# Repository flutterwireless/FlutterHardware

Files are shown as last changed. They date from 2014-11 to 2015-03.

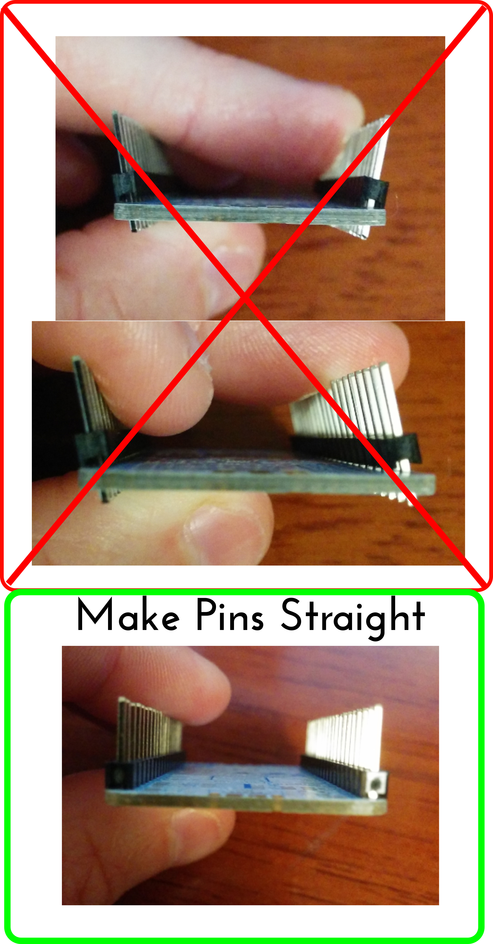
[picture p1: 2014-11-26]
Boards/FlutterBasic/gerber/Solder pins.jpg

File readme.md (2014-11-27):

Flutter Wireless Open Source Hardware files
==============

Flutter Wireless is an open source hardware platform designed by Taylor Alexander for the development of mesh networking protocols and connected devices. It is intended for use in robotics, hobbyist, commercial, or educational applications. For more information visit [FlutterWireless.com](http://www.flutterwireless.com/). All files copyright Flutter Wireless, 2013-2015.

Instructions
----------

If you want to modify these files, you need a version of EagleCAD that can work with 4 layer files (the freeware version only supports 2 layers). They have a [hobby license](http://www.cadsoftusa.com/shop/eagle-hobbyist-and-education/?lang=en) that is well-suited for this. If you only want to reproduce the boards as is, we have provided gerber files. Note that the files do not have a clean perimeter as they are intended to be arrayed on a panel. We will probably revert to a non panel-ready version at some point, as I don't believe our assembler needs them to be that way. Please file an issue if you cannot use them in their current format.

License
--------

This is the initial release of the hardware design files. They are licensed under Creative Commons Attribution-ShareAlike 4.0 International (CC BY-SA 4.0), which is available at: http://creativecommons.org/licenses/by-sa/4.0/
If you use the files, please check them carefully - they may contain errors.

Legal
--------

These documents are provided for informational purposes only and neither Flutter Wireless nor its employees, contributors, or representatives may be held liable for any damages caused by the use of these files. By using these files, you agree to release from all liability and hold harmless Flutter Wireless, its employees, contributors, and representatives. We are not responsible for any errors or ommissions contained herin, and all devices derived from this work should be indepentently verified by an engineer or engineers skilled in the appropriate fields.

The devices described by these files are wireless devices classified as intentional radiators. The electromagnetic spectrum used by these devices is a publicly shared medium that is regulated by all governments worldwide. If you produce your own copies of these boards, you must comply with all local wireless regulations including but not limited to passing wireless certification tests. Flutter Wireless has performed wireless testing to permit us to distribute this hardware in various regions, but this certification is exclusive to Flutter Wireless and does not extend to third party manufacturers. It is your responsibility to know the laws and ensure that devices you produce follow them.

It should also be noted that open source radio products are a new phenomenon. So far the law permits them, but there is a risk that new legal restrictions could be passed that harm the open source community if users abuse this hardware by producing versions of this or other hardware that violate the law. Be respectful and responsible - don't make changes that you don't understand or that violate the law. None of this should be considered legal advice - just common sense.

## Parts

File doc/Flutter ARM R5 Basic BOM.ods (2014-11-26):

Qty | Value | Package | Description | Manufacturer | Manufacturer Part Number | Digikey Part Number |  |  | 500 Pcs |  | 4000 Pcs |  | Designator | Notes
1 | Radio Chip | QFN-32 | 915MHz Radio Chip | Texas Instruments | CC1200 | 296-36396-1-ND | 10 | 500 | 2.21 | 2.21 | 2.21 | 2.21 | U2
1 | Crypto chip | UDFN 8 | Crypto chip | Atmel | ATAES132-MAH-ER-T | ATAES132-MAH-ER-TCT-ND | 5 | 500 | 0.634 | 0.634 | 0.565 | 0.565 | U6
1 | RF Balun | IPC_BALUN_CC1200 | RF Balun | Johanson Technology | 609-0900PC15J0013E |  | 90 | 500 | 0.623 | 0.623 | 0.551 | 0.551 | U5
1 | MIC5235-3.3 | SOT23-5 | 3.3V 0.15A, 16v input | Micrel | MIC5205-3.3YM5 TR | 576-1259-1-ND | 9 | 500 | 0.3 | 0.3 | 0.203 | 0.203 | U1
1 | Lithium Charger | SOT23-5 | Battery Charger | Microchip | MCP73831 | MCP73831T-2ACI/OTCT-ND | 5 | 500 | 0.42 | 0.42 | 0.42 | 0.42 | U4
1 | SAM3S1A | LQFP48 | MCU 32BIT 64KB FLASH | Atmel | ATSAM3S1AB-AUR | ATSAM3S1AB-AURTR-ND | 10 | 500 | 2.73 | 2.73 | 2.44 | 2.44 | U3
 |  |  |  |  |  |  |  | 0 |  | 0 |  | 0
2 | 0.01uF | 0402-CAP | CER 10000PF 16V 10% X7R | Samsung | CL05B103KO5NCNC | 1276-1500-1-ND | 500 | 1000 | 0.00216 | 0.00432 | 0.00151 | 0.00302 | C171, C211
10 | 0.1uF | 0402-CAP | CER 0.1UF 16V Y5V | Yageo | CC0402ZRY5V7BB104 | 311-1047-1-ND | 1000 | 5000 | 0.00255 | 0.0255 | 0.00214 | 0.0214 | C4, C5, C32, C33, C34, C35, C36, C37, C38, C41
1 | 0.22uF | 0402-CAP | CER 0.22UF 10V Y5V | Samsung | CL05F224ZP5NNNC | 1276-1746-2-ND | 250 | 500 | 0.01066 | 0.01066 | 0.00582 | 0.00582 | C61
1 | 1.5nF | 0402-CAP | CER 1500PF 50V 10% X7R | Yageo | CC0402KRX7R9BB152 | 311-1032-2-ND | 500 | 500 | 0.00566 | 0.00566 | 0.00368 | 0.00368 | C231
1 | 100pF | 0402-CAP | CER 100PF 50V 5% NPO | Yageo | CC0402JRNPO9BN101 | 311-1024-2-ND | 10 | 500 | 0.00424 | 0.00424 | 0.00231 | 0.00231 | C172
4 | 15pF | 0402-CAP | CER 15PF 50V 5% NPO | Yageo | CC0402JRNPO9BN150 | 311-1017-1-ND | 500 | 2000 | 0.00297 | 0.01188 | 0.00231 | 0.00924 | C42, C43, C301, C311
1 | 1pF | 0402-CAP | CER 1PF 50V NP0 | Murata | GRM1555C1H1R0BA01D | 490-6206-2-ND | 200 | 500 | 0.00848 | 0.00848 | 0.00594 | 0.00594 | C203
2 | 2.2uF | 0402-CAP | CER 2.2UF 6.3V 20% X5R | Yageo | CC0402MRX5R5BB225 | 311-1442-1-ND | 100 | 1000 | 0.00236 | 0.00472 | 0.00134 | 0.00268 | C39, C40
1 | 33pF | 0402-CAP | CER 33PF 50V 5% NPO | Yageo | CC0402JRNPO9BN330 | 311-1020-2-ND | 200 | 500 | 0.00424 | 0.00424 | 0.00275 | 0.00275 | C173
11 | 47nF | 0402-CAP | CER 0.047UF 6.3V X5R | Murata | GRM155R60J473KA01D | 490-8250-2-ND | 400 | 5500 | 0.007 | 0.077 | 0.00588 | 0.06468 | C11, C51, C121, C131, C151, C221, C251, C261, C271, C281, C291
2 | 4.7uF 24v | 0805-CAP | CER 4.7UF 25V 10% X5R 0805 | Samsung | CL21A475KAQNNNE | 1276-1244-2-ND | 100 | 1000 | 0.02932 | 0.05864 | 0.02505 | 0.0501 | C2, C3
 |  |  |  |  |  |  |  | 0 |  | 0 |  | 0
1 | 0.012uH | 0402-IND | Inductor 12NH 5% 0402 | Taiyo Yuden | HK100512NJ-T | 587-1520-2-ND | 100 | 500 | 0.01376 | 0.01376 | 0.00750 | 0.0075 | L204
1 | 0.01uH | 0402-IND | Inductor 10NH 5% 0402 | Taiyo Yuden | HK100510NJ-T | 587-1519-1-ND | 20 | 500 | 0.01376 | 0.01376 | 0.00750 | 0.0075 | L171
 |  |  |  |  |  |  |  | 0 |  | 0 |  | 0
1 | RED LED | LED-0603 | Charging LED | Lite-On | LTST-C190KRKT | 160-1436-2-ND | 200 | 500 | 0.06732 | 0.06732 | 0.04554 | 0.04554 | D11
1 | RGB LED | P-LCC-4-3 | Reverse emitter RGB LED | SunLED | XZMDKCBDDG45S-9 |  | 10 | 500 | 0.4296 | 0.4296 | 0.4296 | 0.4296 | LED1 | http://www.us.sunled.com/products/spec/XZMDKCBDDG45S-9.pdf
 |  |  |  |  |  |  |  | 0 |  | 0 |  | 0
3 | 0R | 0402-RES | RES 0.0 OHM 1/10W JUMP 0402 SMD | Panasonic | ERJ-2GE0R00X | P0.0JCT-ND | 500 | 1500 | 0.00384 | 0.01152 | 0.00198 | 0.00594 | R18, R19, R201
2 | 10k | 0402-RES | RES 10K OHM 1/10W 5% 0402 SMD | Panasonic | ERJ-2GEJ103X | P10KJCT-ND | 500 | 1000 | 0.00384 | 0.00768 | 0.0027 | 0.0054 | R11, R13
3 | 10R | 0402-RES | RES 10 OHM 1/16W 5% 0402 | Samsung | RC1005J100CS | 1276-4328-1-ND | 1000 | 1500 | 0.00233 | 0.00699 | 0.00132 | 0.00396 | R2, R10, R171
3 | 1k | 0402-RES | RES 1K OHM 1/10W 5% 0402 SMD | Panasonic | ERJ-2GEJ102X | P1.0KJCT-ND | 500 | 1500 | 0.00384 | 0.01152 | 0.00198 | 0.00594 | R3, R6, R21
2 | 27R | 0402-RES | RES 27 OHM 1/16W 5% 0402 | Samsung | RC1005J270CS | 1276-4338-1-ND | 500 | 1000 | 0.0023 | 0.0046 | 0.00130 | 0.0026 | R1, R4
4 | 2k | 0402-RES | RES 2K OHM 1/16W 5% 0402 | Samsung | RC1005J202CS | 1276-4383-1-ND | 500 | 2000 | 0.002 | 0.008 | 0.00130 | 0.0052 | R8, R14, R15, R22
1 | 56K Ohm | 0402-RES | RES 56K OHM 1/16W 5% 0402 SMD | Yageo | RC0402JR-0756KL | 311-56KJRCT-ND | 500 | 500 | 0.00364 | 0.00364 | 0.00192 | 0.00192 | R141
1 | 6.49k | 0402-RES | RES 6.49K OHM 1/16W 1% 0402 SMD | Yageo | RC0402FR-076K49L | 311-6.49KLRTR-ND | 1000 | 500 | 0.00364 | 0.00364 | 0.00192 | 0.00192 | R5
1 | 68R | 0402-RES | RES 68 OHM 1/16W 5% 0402 | Samsung | RC1005J680CS | 1276-4348-2-ND | 1000 | 500 | 0.00312 | 0.00312 | 0.002 | 0.002
 |  |  |  |  |  |  |  | 0 |  | 0 |  | 0
1 | Fuse, 500mA | 0603-PTC | FUSE PTC RESET 500MA SMD 0603 | Bourns, Inc. | MF-FSMF050X-2 | MF-FSMF050X-2CT-ND | 20 | 500 | 0.2136 | 0.2136 | 0.16500 | 0.165 | F1
1 | USB Protection Diode | SOD-323 | DIODE SCHOTTKY 30V 0.5A | NXP | PMEG3005AEA,115 | 568-6509-2-ND | 10 | 500 | 0.1399 | 0.1399 | 0.09396 | 0.09396 | D2
 |  |  |  |  |  |  |  | 0 |  | 0 |  | 0
1 | 12MHz | ABM8G 3.2mm x 2.5mm | CRYSTAL 12MHZ 10PF SMD | Abracon | ABM8G-12.000MHZ-B4Y-T | 535-10283-2-ND | 5 | 500 | 0.446 | 0.446 | 0.325 | 0.325 | X1
1 | 40MHz | FA 128 2mm x 1.6mm | CRYSTAL 40MHZ 10PF SMD | Epson | FA-128 40.0000MF10Z-K3 | SER3753TR-ND | 10 | 500 | 0.68 | 0.68 | 0.559 | 0.559 | X2
 |  |  |  |  |  |  |  | 0 |  | 0 |  | 0
1 | MICRO USB | MICRO-USB-SLOT-2 | CONN USB MICRO B RECPT SMT R/A | FCI | 10118193-0001LF | 609-4616-1-ND | 10 | 500 | 0.26 | 0.26 | 0.158 | 0.158 | U$2
2 | Main Header | 1x20 | 20 Pin SIP Header |  |  |  |  | 1000 | 0.03 | 0.06 | 0.03 | 0.06 | JP2, JP4 | Flush cut pins after soldering
 |  |  |  |  |  |  |  | 0 |  | 0 |  | 0
1 | Dome Array | Two 12mm Snap Dome Array | Adhesive dome array | Custom | provided by customer |  |  | 500 | 0.12 | 0.12 | 0.12 | 0.12 | U$11, U$12 | Hand apply adhesive dome sheet after soldering.
 |  |  |  |  |  |  |  |  | Sum: | 9.63699 |  | 8.5666

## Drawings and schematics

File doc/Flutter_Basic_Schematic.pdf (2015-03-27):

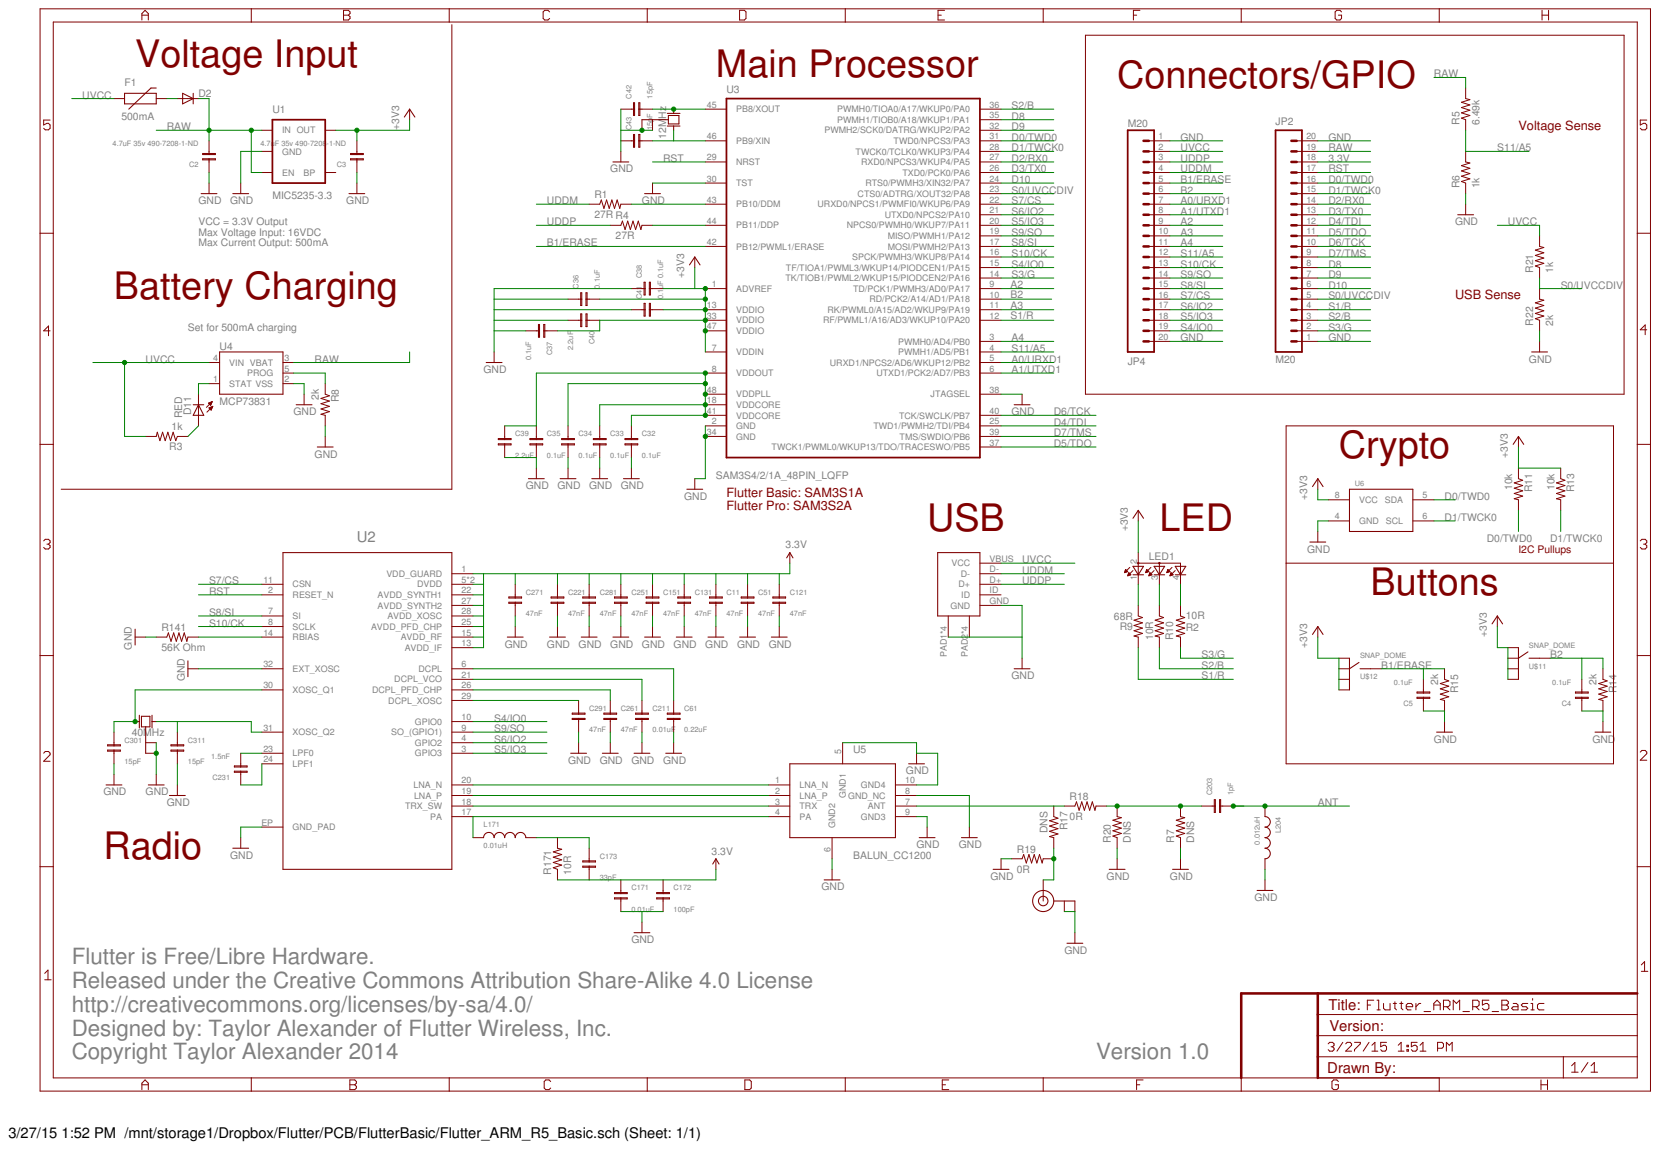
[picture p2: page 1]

33 | | 12 S1/R
47 | | 3 PWMH1/AD5/PB1 A4

GND GND

Flutter is Free/Libre Hardware. Released under the Creative Commons Attribution Share-Alike 4.0 License
http://creativecommons.org/licenses/by-sa/4.0/

3/27/15 1:52 PM /mnt/storage1/Dropbox/Flutter/PCB/FlutterBasic/Flutter_ARM_R5_Basic.sch (Sheet: 1/1)

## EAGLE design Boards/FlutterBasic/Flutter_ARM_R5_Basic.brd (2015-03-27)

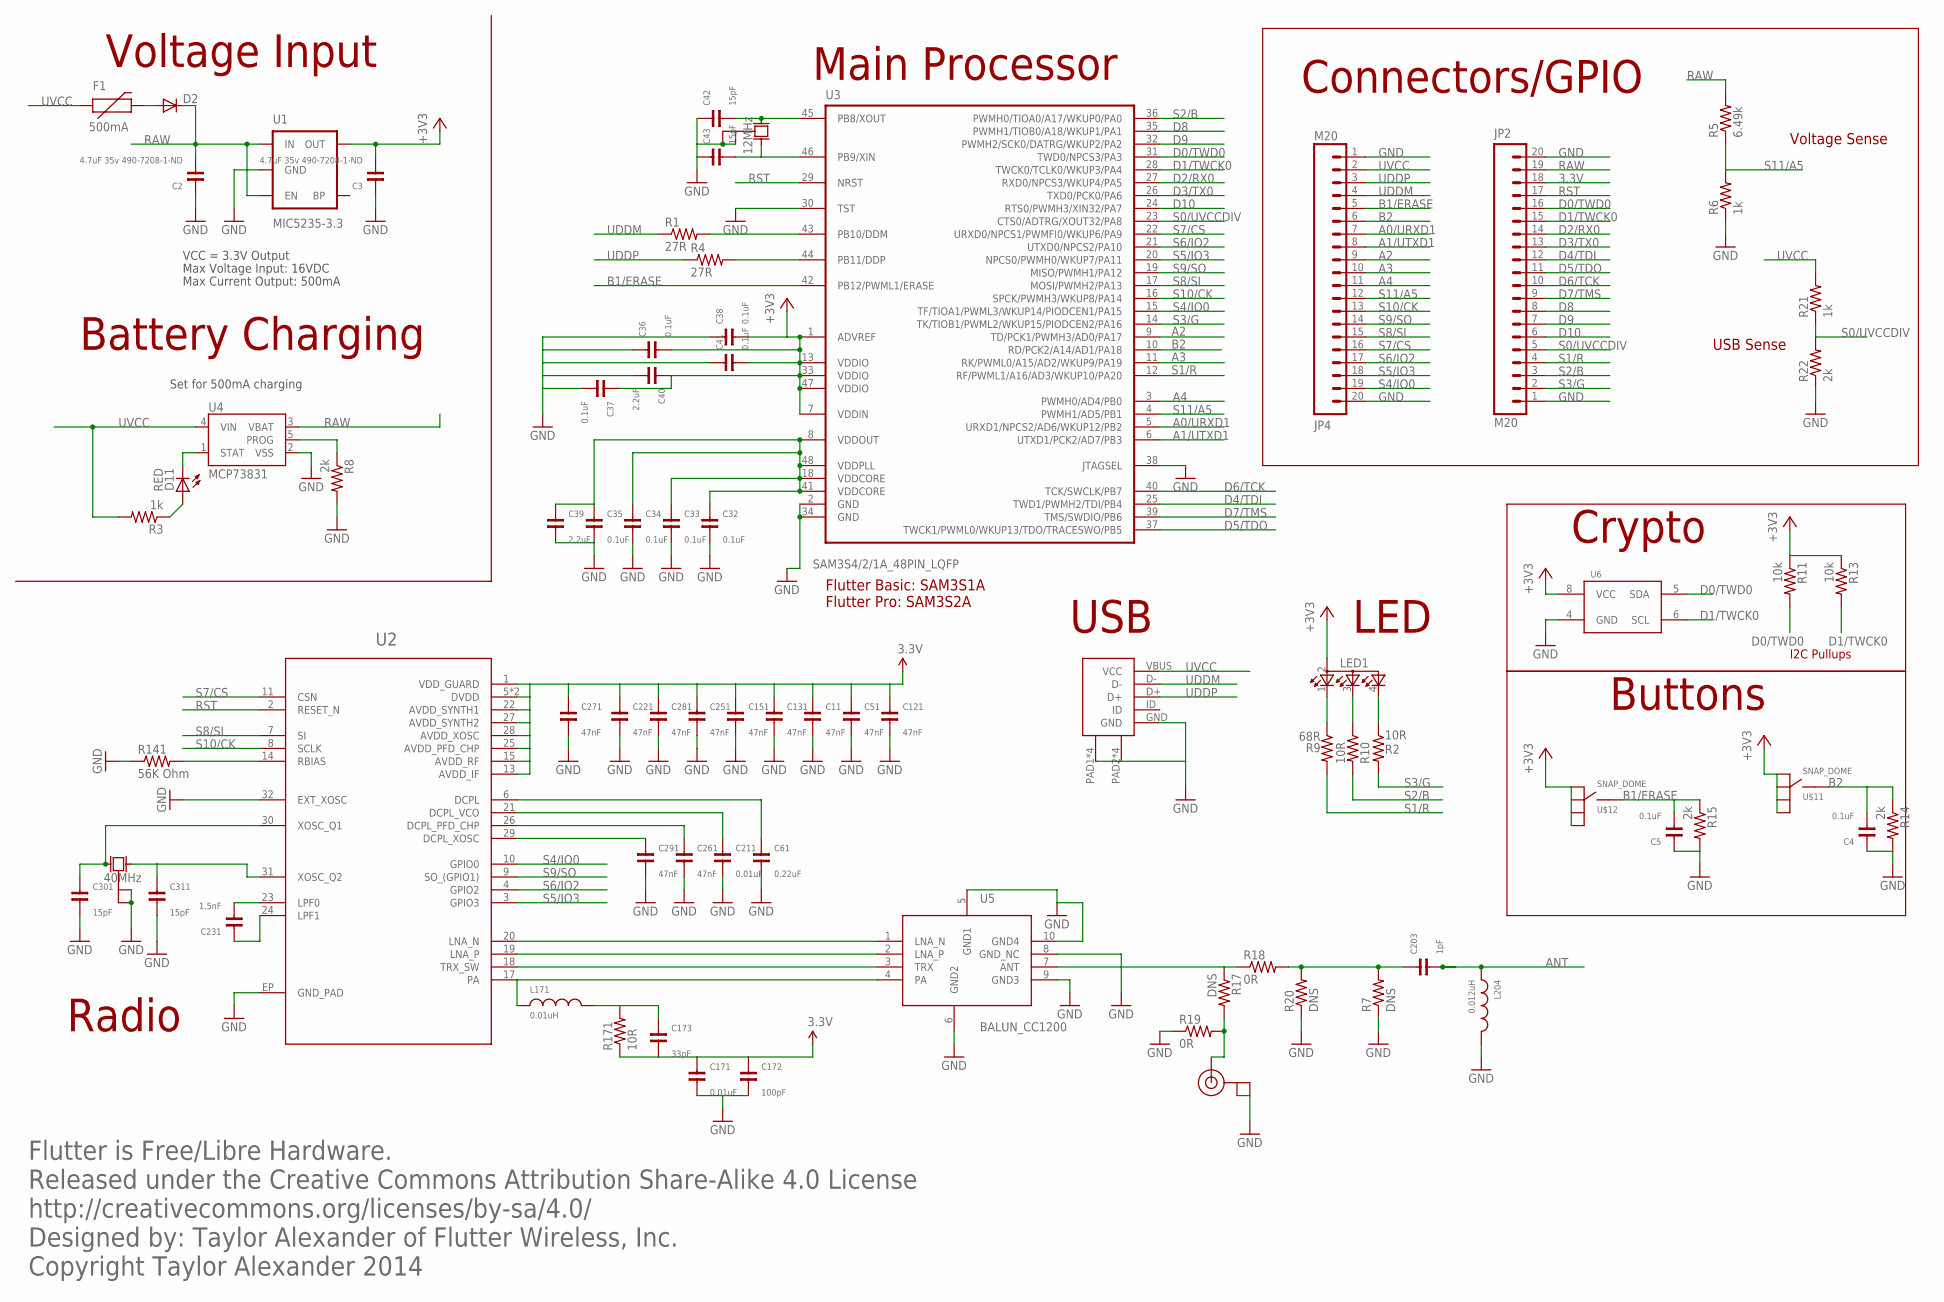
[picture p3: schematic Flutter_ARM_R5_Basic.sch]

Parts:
C2, C3: 4.7uF 35v 490-7208-1-ND; 0808-CAP
C4, C5, C32, C33, C34, C35, C36, C37, C38, C41: 0.1uF; 0402-CAP
C11, C51, C121, C131, C151, C221, C251, C261, C271, C281, C291: 47nF; 0402-CAP
C39, C40: 2.2uF; 0402-CAP
C42, C43, C301, C311: 15pF; 0402-CAP
C61: 0.22uF; 0402-CAP
C171, C211: 0.01uF; 0402-CAP
C172: 100pF; 0402-CAP
C173: 33pF; 0402-CAP
C203: 1pF; 0402-CAP
C231: 1.5nF; 0402-CAP
D2: DIODESOD; SOD-323
D11: RED; LED-0603
F1: 500mA; 0603-PTC
JP2, JP4: M20; 1X20
L171: 0.01uH; 0402-IND
L204: 0.012uH; 0402-IND
LED1: TOPLED-3; P-LCC-4-3
R1, R4: 27R; 0402-RES
R2, R10, R171: 10R; 0402-RES
R3, R6, R21: 1k; 0402-RES
R5: 6.49k; 0402-RES
R7, R17, R20: DNS; 0402-RES
R8, R14, R15, R22: 2k; 0402-RES
R9: 68R; 0402-RES
R11, R13: 10k; 0402-RES
R18, R19: 0R; 0402-RES
R141: 56K Ohm; 0402-RES
U1: MIC5235-3.3; SOT23-5
U2: CC1200; QFN-32
U3: SAM3S4/2/1A_48PIN_LQFP; LQFP48
U4: MCP73831; SOT23-5
U5: BALUN_CC1200; IPC_BALUN_CC1200
U6: ATSHA204/ATECC108UDFN; UDFN_8_ATSHA204
U7: U.FL
U$2: MICRO_USB; MICRO-USB-SLOT-2
U$11, U$12: SNAP_DOME; 12MM_SNAP_DOME_SMALLER
X1: 12MHz; XTAL_ABRACON_ABM8G_3.2MMX2.5MM
X2: 40MHz; XTAL_EPSON_FA_128_2MMX1.6MM

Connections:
3.3V: C3.2, C11.1, C36.2, C37.1, C38.2, C40.1, C41.2, C51.1, C121.1, C131.1, C151.1, C171.1, C172.1, C173.2, C221.1, C251.1, C271.1, C281.1, JP2.18, LED1.2 (A2), R11.1, R13.1, R171.1, U1.5 (OUT), U2.1 (VDD_GUARD), U2.5 (DVDD), U2.12 (DVDD), U2.13 (AVDD_IF), U2.15 (AVDD_RF), U2.22 (AVDD_SYNTH1), U2.25 (AVDD_PFD_CHP), U2.27 (AVDD_SYNTH2), U2.28 (AVDD_XOSC), U3.1 (ADVREF), U3.7 (VDDIN), U3.13 (VDDIO), U3.33 (VDDIO), U3.47 (VDDIO), U6.8 (VCC), U$11.P$1, U$11.P$2, U$11.P$3, U$11.P$4, U$12.P$1, U$12.P$2, U$12.P$3, U$12.P$4
+1.8V: C32.1, C33.1, C34.1, C35.1, C39.1, U3.8 (VDDOUT), U3.18 (VDDCORE), U3.41 (VDDCORE), U3.48 (VDDPLL)
A0/URXD1: JP4.7, U3.5 (URXD1/NPCS2/AD6/WKUP12/PB2)
A1/UTXD1: JP4.8, U3.6 (UTXD1/PCK2/AD7/PB3)
A2: JP4.9, U3.9 (TD/PCK1/PWMH3/AD0/PA17)
A3: JP4.10, U3.11 (RK/PWML0/A15/AD2/WKUP9/PA19)
A4: JP4.11, U3.3 (PWMH0/AD4/PB0)
ANT: C203.2, L204.1
B1/ERASE: C5.2, JP4.5, R15.1, U3.42 (PB12/PWML1/ERASE), U$12.CENTER
B2: C4.2, JP4.6, R14.1, U3.10 (RD/PCK2/A14/AD1/PA18), U$11.CENTER
D0/TWD0: JP2.16, R11.2, U3.31 (TWD0/NPCS3/PA3), U6.5 (SDA)
D1/TWCK0: JP2.15, R13.2, U3.28 (TWCK0/TCLK0/WKUP3/PA4), U6.6 (SCL)
D2/RX0: JP2.14, U3.27 (RXD0/NPCS3/WKUP4/PA5)
D3/TX0: JP2.13, U3.26 (TXD0/PCK0/PA6)
D4/TDI: JP2.12, U3.25 (TWD1/PWMH2/TDI/PB4)
D5/TDO: JP2.11, U3.37 (TWCK1/PWML0/WKUP13/TDO/TRACESWO/PB5)
D6/TCK: JP2.10, U3.40 (TCK/SWCLK/PB7)
D7/TMS: JP2.9, U3.39 (TMS/SWDIO/PB6)
D8: JP2.8, U3.35 (PWMH1/TIOB0/A18/WKUP1/PA1)
D9: JP2.7, U3.32 (PWMH2/SCK0/DATRG/WKUP2/PA2)
D10: JP2.6, U3.24 (RTS0/PWMH3/XIN32/PA7)
GND: C2.1, C3.1, C4.1, C5.1, C11.2, C32.2, C33.2, C34.2, C35.2, C36.1, C37.2, C38.1, C39.2, C40.2, C41.1, C42.1, C43.1, C51.2, C61.2, C121.2, C131.2, C151.2, C171.2, C172.2, C211.2, C221.2, C251.2, C261.2, C271.2, C281.2, C291.2, C301.2, C311.2, JP2.1, JP2.20, JP4.1, JP4.20, L204.2, R6.1, R7.1, R8.2, R14.2, R15.2, R19.1, R20.1, R22.1, R141.1, U1.2 (GND), U2.32 (EXT_XOSC), U2.EP (GND_PAD), U3.2 (GND), U3.30 (TST), U3.34 (GND), U3.38 (JTAGSEL), U4.2 (VSS), U5.5 (GND1), U5.6 (GND2), U5.8 (GND_NC), U5.9 (GND3), U5.10 (GND4), U6.4 (GND), U7.P$1 (GND), U7.P$2 (GND), U$2.GND, U$2.PAD1, U$2.PAD2, U$2.PAD3, U$2.PAD4, U$2.PAD5, U$2.PAD6, U$2.PAD7, U$2.PAD8, X1.P$2 (GND), X1.P$4 (GND), X2.2 (GND), X2.4 (GND)
LNA_N: U2.20 (LNA_N), U5.1 (LNA_N)
LNA_P: U2.19 (LNA_P), U5.2 (LNA_P)
unnamed: C61.1, U2.6 (DCPL)
unnamed: R141.2, U2.14 (RBIAS)
unnamed: C231.1, U2.24 (LPF1)
unnamed: C231.2, U2.23 (LPF0)
unnamed: C211.1, U2.21 (DCPL_VCO)
unnamed: D11.A, R3.1
unnamed: C173.1, L171.2, R171.2
unnamed: C203.1, R7.2, R18.2, R20.2
unnamed: D2.2 (A), F1.2
unnamed: R17.1, R18.1, U5.7 (ANT)
unnamed: R17.2, R19.2, U7.P$3 (SIGNAL)
unnamed: C311.1, U2.31 (XOSC_Q2), X2.1 (X1)
unnamed: C261.1, U2.26 (DCPL_PFD_CHP)
unnamed: C301.1, U2.30 (XOSC_Q1), X2.3 (X2)
unnamed: C291.1, U2.29 (DCPL_XOSC)
unnamed: LED1.1 (CRED), R9.1
unnamed: LED1.4 (CGREEN), R2.1
unnamed: C42.2, U3.45 (PB8/XOUT), X1.P$3 (X2)
unnamed: C43.2, U3.46 (PB9/XIN), X1.P$1 (X1)
PA: L171.1, U2.17 (PA), U5.4 (PA)
PROG: R8.1, U4.5 (PROG)
RAW: C2.2, D2.1 (C), JP2.19, R5.2, U1.1 (IN), U1.3 (EN), U4.3 (VBAT)
RST: JP2.17, U2.2 (RESET_N), U3.29 (NRST)
S0/UVCCDIV: JP2.5, R21.1, R22.2, U3.23 (CTS0/ADTRG/XOUT32/PA8)
S1/R: JP2.4, R9.2, U3.12 (RF/PWML1/A16/AD3/WKUP10/PA20)
S2/B: JP2.3, R10.2, U3.36 (PWMH0/TIOA0/A17/WKUP0/PA0)
S3/G: JP2.2, R2.2, U3.14 (TK/TIOB1/PWML2/WKUP15/PIODCEN2/PA16)
S4/IO0: JP4.19, U2.10 (GPIO0), U3.15 (TF/TIOA1/PWML3/WKUP14/PIODCEN1/PA15)
S5/IO3: JP4.18, U2.3 (GPIO3), U3.20 (NPCS0/PWMH0/WKUP7/PA11)
S6/IO2: JP4.17, U2.4 (GPIO2), U3.21 (UTXD0/NPCS2/PA10)
S7/CS: JP4.16, U2.11 (CSN), U3.22 (URXD0/NPCS1/PWMFI0/WKUP6/PA9)
S8/SI: JP4.15, U2.7 (SI), U3.17 (MOSI/PWMH2/PA13)
S9/SO: JP4.14, U2.9 (SO_(GPIO1)), U3.19 (MISO/PWMH1/PA12)
S10/CK: JP4.13, U2.8 (SCLK), U3.16 (SPCK/PWMH3/WKUP8/PA14)
S11/A5: JP4.12, R5.1, R6.2, U3.4 (PWMH1/AD5/PB1)
STAT: D11.C, U4.1 (STAT)
TRX_SW: U2.18 (TRX_SW), U5.3 (TRX)
U7: LED1.3 (CBLUE), R10.1
UDDC_+: R4.2, U3.44 (PB11/DDP)
UDDC_-: R1.2, U3.43 (PB10/DDM)
UDDM: JP4.4, R1.1, U$2.D-
UDDP: JP4.3, R4.1, U$2.D+
UVCC: F1.1, JP4.2, R3.2, R21.2, U4.4 (VIN), U$2.VBUS (VCC)

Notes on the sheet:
Max Voltage Input: 16VDC
Max Current Output: 500mA
VCC = 3.3V Output
Flutter is Free/Libre Hardware. Released under the Creative Commons Attribution Share-Alike 4.0 License http://creativecommons.org/licenses/by-sa/4.0/ Designed by: Taylor Alexander of Flutter Wireless, Inc. Copyright Taylor Alexander 2014
I2C Pullups
Set for 500mA charging
Voltage Input
Battery Charging
Main Processor
Connectors/GPIO
Radio
Buttons
Crypto
USB
LED
Flutter Basic: SAM3S1A Flutter Pro: SAM3S2A
Voltage Sense
USB Sense

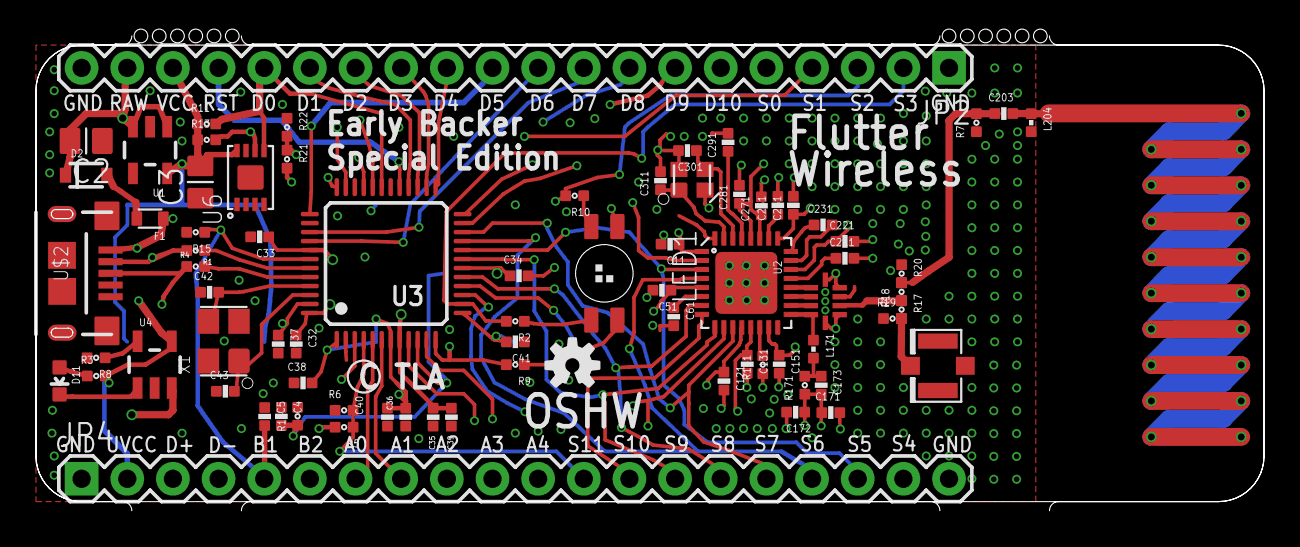
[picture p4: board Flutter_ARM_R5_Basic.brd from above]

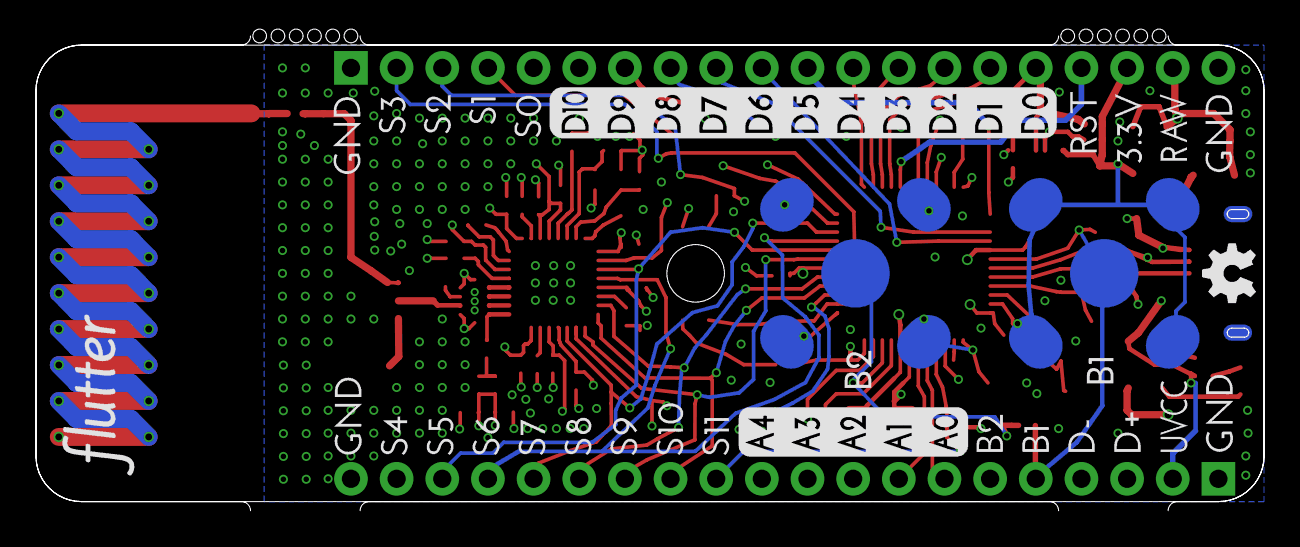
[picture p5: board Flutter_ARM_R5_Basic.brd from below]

Board: 4 copper layers, 68.3 x 26.4 mm, 79 parts (2 on the bottom side), 67 nets.

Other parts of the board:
U$1: OSHW-LOGOS; OSHW-LOGO-S

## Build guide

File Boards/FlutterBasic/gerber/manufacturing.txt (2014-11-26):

Order information:
white soldermask, blue silkscreen, two sides silk, 1.24mm thickness, 4 layers, gold finishing, electrical testing

*.GTL Layer 1 (top)
*.G2L Layer 2
*.G3L Layer 3
*.GBL Layer 4 (bottom)
*.GTS Top Soldermask
*.GBS Bottom Soldermask
*.GTO Top Silkscreen
*.GBO Bottom Silkscreen
*.GKO Board Outline
*.XLN Drills
*.MLL Milling (pre-plating)

PCB DESCRIPTION:4 LAYER PCB 1.24 MM nominal
Copper        1   35 um
Dielectric  1-2   0.4 mm (e.g. 2x Prepreg 7628 AT05 47% Resin)
Copper        2   35 um
Dielectric  2-3   0.3 mm (2 x 2157 49% Resin)
Copper        3   35 um
Dielectric  3-4   0.4 mm (e.g. 2x Prepreg 7628 AT05 47% Resin)
Copper        4   35 um

DE104iML or equivalent substrate (Resin contents around 45%, which gives Er=4.45@1GHz, TanD=0.016)

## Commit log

2014-11-26 initial commit, Flutter Wireless first release.
    [Flutter ARM R5 Basic BOM.ods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]
2015-03-27 Reorganized schematic, generated PDF schematic.
    [Flutter_ARM_R5_Basic.brd, Flutter_ARM_R5_Basic.sch]
2015-03-27 Added version number, changed schematic name.
    [Flutter_ARM_R5_Basic.sch]
2015-03-27 Re-added schematic PDF, which was left out last commit.
2015-03-27 Removed spaces from schematic name for nicer URL.

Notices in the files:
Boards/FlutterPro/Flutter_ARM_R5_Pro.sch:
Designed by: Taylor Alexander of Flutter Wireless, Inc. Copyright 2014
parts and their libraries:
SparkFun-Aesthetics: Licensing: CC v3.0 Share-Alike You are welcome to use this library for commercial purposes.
